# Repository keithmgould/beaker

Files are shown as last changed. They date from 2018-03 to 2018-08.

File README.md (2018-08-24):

# Beaker Robot

## Brief Compute Breakdown

### Raspberry Pi

This is used for Beaker's "high level" control, in particular any neural network control algorithms are stored here.

### Arduino Mega

This is used for Beaker's "low level" control. It can take commands from the "high level" Raspberry Pi. It handles all the details of Beaker's physical components, like input sensors, telemetry transmission, and motor control.

## Software Breakdown

Since Beaker utilizes both an Arduino and a Raspberry Pi, code is broken up into two main directories named (drum roll...) arduino and raspberry_pi.

### Arduino

#### arduino/lib

The bulk of Beaker's Arduino code is housed in the `arduino/lib` directory. Here you will find literally all functionality wrapped in classes. Each lib has a header comment explaining the libs role.

#### arduino/controllers

The controllers realize balance and basic functionality. There are some oldies but goodies, like pid_control. Each controller
has a header-comment explaining what it does. Of note is the `rPI_control`, which is the controller that acts as a middle-man 
between the Raspberry Pi and Beaker's body. This is the controller used for any neural-network control.

When working with any of the non-neural network controllers, such as PID, you can easily interact with Beaker wirelessly via the 
`raspberry_pi/terminal/arduino.py` script. Once the arduino app is loaded and running, ssh into the pi, run the script and type
`H` to see a list of options for how to interact (and tune) the controller you are playing with. 

#### arduino/system_checks

The system checks directory holds a bunch of arduino scripts that allow the developer to
interactively test out the functionality of Beaker as well as the low-level libraries that makes Beaker 
work. For example, there is an 'encoders' script that lets the developer turn the wheels (by hand)
and see in the serial output that the encoders are working. It's important that the 
underlying code works before attempting to lay on more complicated algorithms. The README
in System_checks has some suggestions about the ordering in which someone performs the checks.
Note that these are not needed to run before each use. They are there in case things go wrong,
and you want to find out where exactly in hardware/software things are failing.

### Raspberry_Pi

This directory holds the python-based raspberry pi scripts. These are primarily Tensorflow-based neural-networks
that usilize the `rPI_control` arduino app mentioned above.

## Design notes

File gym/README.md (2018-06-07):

Want to use a "realistic" Beaker Bot in simulation with the help of the Bullet Physics engine,
and OpenAI Gym? Great!

##### Primary Files

0. beaker.urdf - the Universal Robot Description File. describes the actual model of Beaker.
0. beakerBot.py - the BeakerBot class that wraps the URDF file.
0. beakerEnv.py - the gym environment that makes use of the BeakerBot class
0. client.py - holds your control algorithm

#### Using it

```
$python3 pidClient.py
```

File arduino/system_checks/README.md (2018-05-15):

## System Checks

These System Checks are isolated pieces of Beaker's functionality, 
meant to ensure higher level, more abstract code is sitting on sane code.

They are not tests (not unit tests, etc..), they are meant to be run on 
Beaker's arduino and print information on Serial Out to prove out basic 
low-level functionality.

Each system check tells you exactly what to check for in the comments.

### Suggested Order of System Checks if using Serial for Motor Control:

1. Encoders
2. rawSerialMotor
3. serialMotor
4. wheels_pid
5. wheels

### Suggested Order of System Checks if using PWM for Motor Control:

1. Encoders
2. rawPWMMotor
3. servoMotor
4. wheels_pid
5. wheels

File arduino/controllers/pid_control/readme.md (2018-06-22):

# Classic Control

Taking the below concept and applying PID to each of the states, rather than just P on each state.

In short, given four element vector that defines the state:

theta, thetaDot, phi, phiDot,

We can apply a PID controller to each of these elements, and sum them together:

outTheta = thetaPid(theta)
outThetaDot = thetaDotPid(theta)
outphi = phiPid(phi)
outphiDot = phiDotPid(phiDot)

then final command is a sum of these:

outTheta + outThetaDot + outPhi + outPhiDot

This command is interpreted as an acceleration, aka a change in desired wheel velocity.

# Original P4 Concept

http://www.geology.smu.edu/~dpa-www/robo/nbot/bal2.txt

David Anderson wrote the following:

---

The Algorithm for two-wheel balancing robot nBot.

The balancing algorithm measures two outputs from the
robot and calculates the torque forces from the motors
needed for balance.  Here is an ascii-art block diagram:

               +---------------------+--------------+
    +--------< | Motor shaft encoder |              |
    |          +---------------------+   Motor PWM  | <-----+
    |    +---< | Angle sensor        |              |       |
    |    |     +---------------------+--------------+       |
    |    |                                                  |
    |    |     +-------+      |\ angle                      |
    |    |     |       |      | \ velocity                  |
    |    +-----| Deriv |------|K1-----+                     |
    |    |     |       |      | /      \                    |
    |    |     +-------+      |/        \                   |
    |    |                               +-----+            |
    |    |                    |\ angle   |      \           |
    |    |                    | \ pos    |       \          |
    |    +--------------------|K2--------+        \         |
    |                         | /        |         \        |
    |                         |/         |          \       |
    |                                    |  SUM      +------+
    |          +-------+      |\ wheel   |          /
    |          |       |      | \velocity|         /
    +----------| Deriv |------|K3--------+        /
    |          |       |      | /        |       /
    |          +-------+      |/         |      /
    |                                    +-----+
    |                         |\ wheel  /
    |                         | \ pos  /
    +-------------------------|K4-----+
                              | /
                              |/

The boxes labled "Deriv" calculate the derivative of the inputs
by subtracting the last sample from the current sample.  For the
shaft encoders this gives the wheel velocity, and for the angle
sensor this gives the angle velocity.  The four triangles labeled
K1 through K4 are the "knobs" that apply gain to the four feedback
signals.  They are then summed together and fed back to the robot
as the PWM motor voltage.

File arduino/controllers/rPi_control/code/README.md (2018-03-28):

## Role: The Arduino acts as Beaker's nervous system:

0. receives (and buffers) the motor quadrature encoders interrupt signals.
0. commands the motors
0. communicates with the IMU
0. communicates with the winch (Add link to repo here)
0. prepares the "state" for the Raspberry Pi (brain) and sends it up upon  request

## Why Not Skip the Arduino?

It's probably possible to skip the Arduino entirely. The reason I didn't is because having
dedicated hardware (and processing power) to lower level functions seemed (and seems) like
a good idea. The quad-encoders for example, send interrupts 300 times per single
revolution of a wheel. Two wheels mean 600 interrupts per second. I'd rather keep that
noise away from the hardware handling the neural network.

## Relevant Files:

0. arduino.ino - the main arduino file to compile (and upload to robot)
0. servoMotor.cpp - small class to encapsulate controlling motors and quad encoders
0. constants.cpp - holds the (you guessed it) constants for the ardduino app

# Functionality Checks:

These are micro progams that load just enough code to test specific parts of
Beaker's hardware.

## Dependencies:

0. Wire.h - allows I2C communication. (this is a core Arduino lib)
0. SabertoothSimplified.h - https://www.dimensionengineering.com/info/arduino

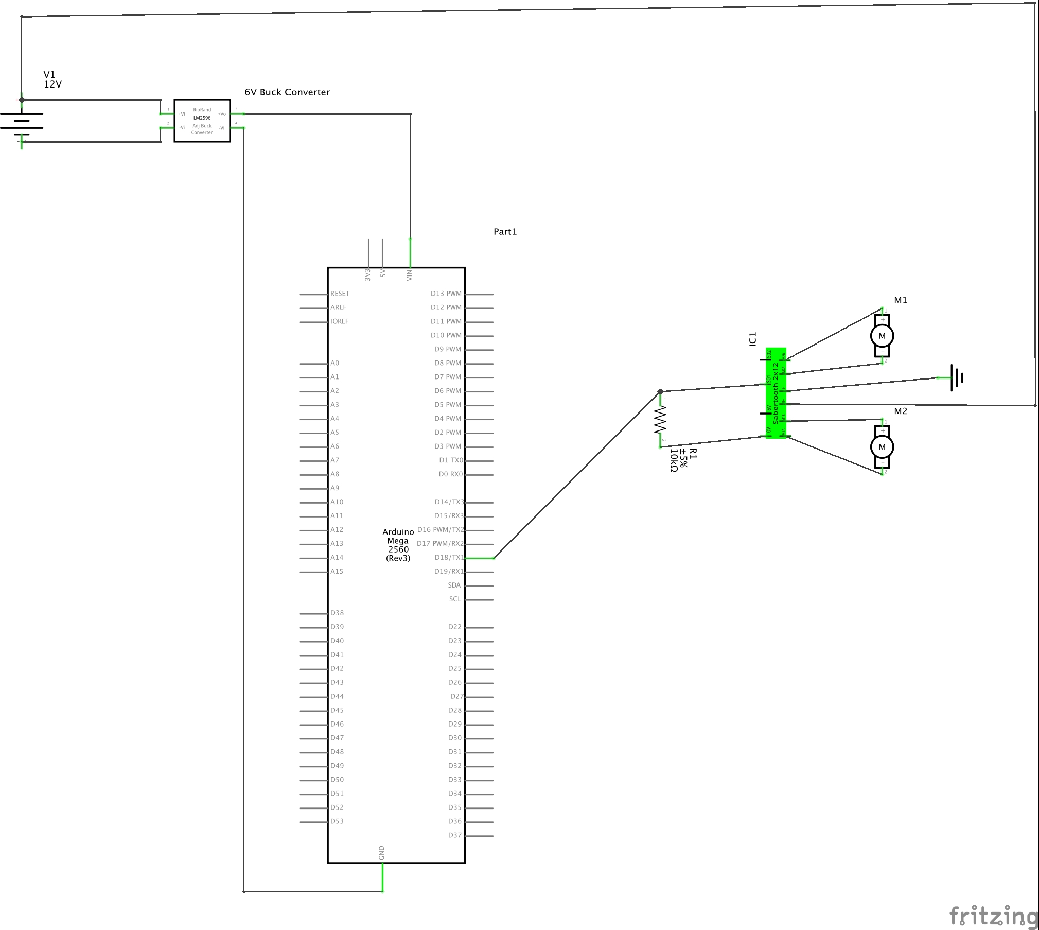
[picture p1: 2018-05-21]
schematics/main_schema.jpg

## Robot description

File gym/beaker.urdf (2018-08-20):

<?xml version="1.0"?>
<robot name="beaker">

    <!-- colors ................................................................. -->
    <material name="red">
      <color rgba="0.8 0 0 1"/>
    </material>
  
   <material name="green">
      <color rgba="0 0.8 0 0.75"/>
    </material>
  
    <material name="blue">
      <color rgba="0 0 0.8 1"/>
    </material>
  
    <material name="orange">
      <color rgba="0.8 0.4 0 0.75"/>
    </material>
  
    <material name="pink">
      <color rgba="1 0.5 0.5 1"/>
    </material>
    
    <material name="gray">
      <color rgba="0.7 0.7 0.7 1"/>
    </material>
    <!-- main body (base) .................................................................-->
  
    <link name="body">
      <visual>
        <geometry>
          <box size="0.1016 0.0254 0.6604"/>
        </geometry>
        <origin xyz="0 0 0.3302" />
        <material name="gray"/>
      </visual>
  
      <!-- axle -->
      <visual>
        <geometry>
          <cylinder length="0.17" radius=".01"/>
        </geometry>
        <origin rpy="0 1.5707963 0" xyz="0 0 0.01905"/>
        <material name="gray"/>
      </visual>
  
      <collision>
        <geometry>
          <box size="0.1016 0.0254 0.6604"/>
        </geometry>
        <origin xyz="0 0 0.3302" />
      </collision>
      <inertial>
        <origin rpy="0 0 0" xyz="0 0 0.2159"/>
        <mass value="1.767" />
        <inertia ixx="0.01" ixy="0.0" ixz="0.0" iyy="0.01" iyz="0.0" izz="0.01"/>
      </inertial>
    </link>

    <!-- right Wheel .................................................................-->
    <link name="right_wheel">
      <visual>
        <geometry>
          <cylinder length="0.0254" radius="0.042"/>
        </geometry>
        <origin rpy="0 1.5708 0"/>
        <material name="green"/>
      </visual>
      <collision>
        <geometry>
          <cylinder length="0.0254" radius="0.042"/>
        </geometry>
        <origin rpy="0 1.5708 0"/>
      </collision>
      <inertial>
        <mass value=".1" />
        <inertia ixx="0.00004453" ixy="0.0" ixz="0.0" iyy="0.00004453" iyz="0.0" izz="0.00007938"/>
      </inertial>
    </link>
  
    <joint name="base_to_right_wheel" type="revolute">
      <limit lower="-0.0756" upper="0.0756" effort="1000" velocity="1000"/>
      <origin xyz="0.09398 0 0.01905"/>
      <parent link="body"/>
      <child link="right_wheel"/>
      <axis xyz="1 0 0"/>
    </joint>
  

    <!-- left Wheel .................................................................-->
    <link name="left_wheel">
      <visual>
        <geometry>
          <cylinder length="0.0254" radius="0.042"/>
        </geometry>
        <origin rpy="0 1.5708 0"/>
        <material name="red"/>
      </visual>
      <collision>
        <geometry>
          <cylinder length="0.0254" radius="0.042"/>
        </geometry>
        <origin rpy="0 1.5708 0"/>
      </collision>
      <inertial>
        <mass value=".1" />
        <inertia ixx="0.00004453" ixy="0.0" ixz="0.0" iyy="0.00004453" iyz="0.0" izz="0.00007938"/>
      </inertial>
    </link>
  
    <joint name="base_to_left_wheel" type="revolute">
      <limit lower="-0.0756" upper="0.0756" effort="1000" velocity="1000"/>
      <origin xyz="-0.09398 0 0.01905"/>
      <parent link="body"/>
      <child link="left_wheel"/>
      <axis xyz="1 0 0"/>
    </joint>

</robot>

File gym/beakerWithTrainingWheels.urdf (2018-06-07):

<?xml version="1.0"?>
<robot name="beaker">
  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
  <link name="body">
    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

    <inertial>
      <origin rpy="0 0 0" xyz="0 0 0.2159"/>
      <mass value="1.767" />

      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
    </inertial>
  </link>

  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
  <link name="face">
    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
    <inertial>
      <mass value="0" />
      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
    </inertial>
  </link>
  <joint name="face_joint" type="fixed">
    <parent link="body"/>
    <child link="face"/>
  </joint>

  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
  <link name="right_wheel">

    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

    <inertial>
      <origin rpy="0 0 0" xyz="0 0 0.2159"/>
      <mass value="0.09" />

      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
    </inertial>
  </link>

  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
  <joint name="base_to_right_wheel" type="continuous">
    <parent link="body"/>
    <child link="right_wheel"/>
    <origin xyz="0.09398 0.0 0.01905" />
    <axis xyz="1 0 0"/>
  </joint>

  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
  <link name="right_wheel_stripe">
    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
    <inertial>
      <mass value="0" />
      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
    </inertial>
  </link>
  <joint name="right_wheel_to_stripe" type="fixed">
    <parent link="right_wheel"/>
    <child link="right_wheel_stripe"/>
  </joint>

  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
  <link name="left_wheel">
    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

    <inertial>
      <origin rpy="0 0 0" xyz="0 0 0.2159"/>
      <mass value="0.09" />

      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
    </inertial>
  </link>

  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
  <joint name="base_to_left_wheel" type="continuous">
    <parent link="body"/>
    <child link="left_wheel"/>
    <origin xyz="-0.09398 0.0 0.01905" />
    <axis xyz="1 0 0"/>
  </joint>

  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
  <link name="left_wheel_stripe">
    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
    <inertial>
      <mass value="0" />
      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
    </inertial>
  </link>
  <joint name="left_wheel_to_stripe" type="fixed">
    <parent link="left_wheel"/>
    <child link="left_wheel_stripe"/>
  </joint>

  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
  <link name="front_training_wheel_strut">
    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 

    <inertial>
      <origin rpy="0 0 0" xyz="0 0 0"/>
      <mass value="0.000001" />
      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
    </inertial>
  </link>
  <joint name="front_strut_joint" type="fixed">
    <parent link="body"/>
    <child link="front_training_wheel_strut"/>
  </joint>

  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
  <link name="left_wheel_front">
    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

    <inertial>
      <origin rpy="0 0 0" xyz="0 0 0.2159"/>
      <mass value="0.001" />

      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
    </inertial>
  </link>

  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
  <joint name="front_strut_to_front_left_wheel" type="continuous">
    <parent link="front_training_wheel_strut"/>
    <child link="left_wheel_front"/>
    <origin xyz="-0.09398 0.42 0.01905" />
    <axis xyz="1 0 0"/>
  </joint>

  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
  <link name="right_wheel_front">
    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

    <inertial>
      <origin rpy="0 0 0" xyz="0 0 0.2159"/>
      <mass value="0.001" />

      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
    </inertial>
  </link>

  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
  <joint name="front_strut_to_front_right_wheel" type="continuous">
    <parent link="front_training_wheel_strut"/>
    <child link="right_wheel_front"/>
    <origin xyz="0.09398 0.42 0.01905" />
    <axis xyz="1 0 0"/>
  </joint>

    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
  <link name="right_wheel_front_stripe">
    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
    <inertial>
      <mass value="0" />
      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
    </inertial>
  </link>
  <joint name="right_wheel_front_to_stripe" type="fixed">
    <parent link="right_wheel_front"/>
    <child link="right_wheel_front_stripe"/>
  </joint>

  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
   <link name="rear_training_wheel_strut">
    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 
    <inertial>
      <origin rpy="0 0 0" xyz="0 0 0"/>
      <mass value="0.0001" />
      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
    </inertial>
  </link>
  <joint name="rear_strut_joint" type="fixed">
    <parent link="body"/>
    <child link="rear_training_wheel_strut"/>
  </joint>

  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
  <link name="right_wheel_rear">
    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

    <inertial>
      <origin rpy="0 0 0" xyz="0 0 0.2159"/>
      <mass value="0.001" />

      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
    </inertial>
  </link>

  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
  <joint name="rear_strut_to_rear_right_wheel" type="continuous">
    <parent link="rear_training_wheel_strut"/>
    <child link="right_wheel_rear"/>
    <origin xyz="0.09398 -0.42 0.01905" />
    <axis xyz="1 0 0"/>
  </joint>

  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
  <link name="right_wheel_rear_stripe">
    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
    <inertial>
      <mass value="0" />
      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
    </inertial>
  </link>
  <joint name="right_wheel_rear_to_stripe" type="fixed">
    <parent link="right_wheel_rear"/>
    <child link="right_wheel_rear_stripe"/>
  </joint>

  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
  <link name="left_wheel_rear">
    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

    <inertial>
      <origin rpy="0 0 0" xyz="0 0 0.2159"/>
      <mass value="0.001" />

      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
    </inertial>
  </link>

  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
  <joint name="rear_strut_to_rear_left_wheel" type="continuous">
    <parent link="rear_training_wheel_strut"/>
    <child link="left_wheel_rear"/>
    <origin xyz="-0.09398 -0.42 0.01905" />
    <axis xyz="1 0 0"/>
  </joint>

  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
  <link name="left_wheel_rear_stripe">
    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
    <inertial>
      <mass value="0" />
      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
    </inertial>
  </link>
  <joint name="left_wheel_rear_to_stripe" type="fixed">
    <parent link="left_wheel_rear"/>
    <child link="left_wheel_rear_stripe"/>
  </joint>

</robot>

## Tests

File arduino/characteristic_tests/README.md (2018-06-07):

## Characteristic Tests

This directory holds tests that are used to help determine constants exhibited by Beaker that 
can be used in the virtual model of Beaker, to help that model be more realistic.

0. wheelSlowdown brings the wheels up to 10 rads/sec, then times how long it takes for them to stop once the power is shut off. This time can be used when setting friction values in the model.

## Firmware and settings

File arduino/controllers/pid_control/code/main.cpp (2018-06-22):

#include <Adafruit_Sensor.h>            // IMU
#include <Adafruit_BNO055.h>            // IMU
#include <Wire.h>                       // I2C for IMU
#include <EEPROM.h>
#include <StandardCplusplus.h>
#include <stdlib.h>
#include <string>
#include <sstream>                      // stringstream
#include "../../../lib/includes.h"     // common Beaker functionality

Pid thetaPid(POSITION_CONTROL_TIMESTEP);
Pid thetaDotPid(POSITION_CONTROL_TIMESTEP);
Pid xPosPid(POSITION_CONTROL_TIMESTEP);
Pid phiDotPid(POSITION_CONTROL_TIMESTEP);

Imu my_imu;
Wheels wheels;
PiTalk piTalk;
Waiter outerWaiter(POSITION_CONTROL_TIMESTEP);
Waiter innerWaiter(MOTOR_CONTROL_TIMESTEP);
bool motorsOn = true;
float momentumConstant = 0;

void leftEncoderEvent(){ wheels.leftEncoderEvent(); }
void rightEncoderEvent(){ wheels.rightEncoderEvent(); }

void printStuff(float dt, float newRadPerSec, float radPerSecDelta, float phiDotAvg, float thetaTerm, float thetaDotTerm, float xPosTerm, float phiDotTerm){
  String log = String(dt);

  // raw states
  log += "," + String(my_imu.getTheta(),4) + "," + String(my_imu.getThetaDot(),4);
  log += "," + String(wheels.getTotalPhi(),4) + "," + String(phiDotAvg,4);

  // calibrations
  log += "," + String(my_imu.getThetaOffset(),4);

  // final result
  log += "," + String(newRadPerSec,4);
  
  // PID term components
  log += "," + String(thetaPid.getTermString());
  log += "," + String(thetaDotPid.getTermString());
  log += "," + String(xPosPid.getTermString());
  log += "," + String(phiDotPid.getTermString());

  // PID final term  
  log += "," + String(thetaTerm,4);
  log += "," + String(thetaDotTerm,4);
  log += "," + String(xPosTerm,4);
  log += "," + String(phiDotTerm,4);

  // Extra
  log += "," + String(wheels.getPhiDot(),4);
  log += "," + String(radPerSecDelta,4);
  log += "," + String(momentumConstant,4);

  Serial3.println(log);
}

// Local memory only. Not EEPROM
void zeroAllParameters(bool tellPi){
  thetaPid.updateParameters(0,0,0);
  thetaDotPid.updateParameters(0,0,0);
  xPosPid.updateParameters(0,0,0);
  phiDotPid.updateParameters(0,0,0);
  wheels.updateRadsPerSec(0);
  momentumConstant = 0;

  if(tellPi){ piTalk.sendToPi("Values Zeroed."); }
}

// in EEPROM
void storeAllParameters(){
  unsigned int addr = 0;
  addr = thetaPid.storeParameters(addr);
  addr = thetaDotPid.storeParameters(addr);
  addr = xPosPid.storeParameters(addr);
  addr = phiDotPid.storeParameters(addr);
  addr = EepromHelper::storeFloat(momentumConstant, addr);

  piTalk.sendToPi("Values Saved to EEPROM.");
}

// from EEPROM
void loadAllParameters(){
  unsigned int addr = 0;
  addr = thetaPid.loadParameters(addr);
  addr = thetaDotPid.loadParameters(addr);
  addr = xPosPid.loadParameters(addr);
  addr = phiDotPid.loadParameters(addr);
  EepromHelper::loadFloat(momentumConstant, addr);

  piTalk.sendToPi("Values Loaded from EEPROM.");
}

void showParamValues(){
  String response = "(T)heta: " + thetaPid.getParamString() + "\n";
  response += "theta(D)ot: " + thetaDotPid.getParamString() + "\n";
  response += "(X)Pos: " + xPosPid.getParamString() + "\n";
  response += "(P)hiDot: " + phiDotPid.getParamString() + "\n";
  response += "MotorsOn: " + String(motorsOn) + "\n";
  response += "MomentumConstant: " + String(momentumConstant) + "\n";

  piTalk.sendToPi(response);
}

void updatePidParameters(int component, std::string message){
  float paramVals[3] = {}; // all zeros
  piTalk.stringToFloats(message, paramVals);
  switch(component){
    case 0:
      thetaPid.updateParameters(paramVals[0], paramVals[1], paramVals[2]);
      break;
    case 1:
      thetaDotPid.updateParameters(paramVals[0], paramVals[1], paramVals[2]);
      break;
    case 2:
      xPosPid.updateParameters(paramVals[0], paramVals[1], paramVals[2]);
      break;
    case 3:
      phiDotPid.updateParameters(paramVals[0], paramVals[1], paramVals[2]);
      break;
  }

  piTalk.sendToPi("Updated PID Parameters.");
}

void turnMotorsOn(){ motorsOn = true; piTalk.sendToPi("Motors Turned ON."); }
void turnMotorsOff(){ motorsOn = false; piTalk.sendToPi("Motors Turned OFF."); }

void updateMomentumConstant(std::string message){
  float newMC = String(message.c_str()).toFloat();
  momentumConstant = newMC;
  piTalk.sendToPi("Updated Momentum Constant.");
}

void showHelp(){
  String response = "T: update theta PID terms. Ex: T0.5 -2.4 8.2\n";
  response += "D: update thetaDot PID terms. Ex: D0.5 -2.4 8.2\n";
  response += "X: update xPos PID terms. Ex: X0.5 -2.4 8.2\n";
  response += "P: update phiDot PID terms. Ex: P0.5 -2.4 8.2\n";
  response += "A: update momentumConstant. Ex: A0.5\n";
  response += "L: load PID values from EEPROM\n";
  response += "S: save PID values to EEPROM\n";
  response += "V: show currently used Param Values\n";
  response += "Z: zero out all PID Values.\n";
  response += "J: enable motors. (Pay attention to motor commands)\n";
  response += "K: disable motors. (Ignore motor commands)\n";
  response += "H: this help\n";

  piTalk.sendToPi(response);
}

void handlePiTalk(char command, std::string message){
  switch(command){
    case 'T': updatePidParameters(0, message); break;
    case 'D': updatePidParameters(1, message); break;
    case 'X': updatePidParameters(2, message); break;
    case 'P': updatePidParameters(3, message); break;
    case 'A': updateMomentumConstant(message); break;
    case 'S': storeAllParameters(); break;
    case 'L': loadAllParameters(); break;
    case 'V': showParamValues(); break;
    case 'Z': zeroAllParameters(true); break;
    case 'J': turnMotorsOn(); break;
    case 'K': turnMotorsOff(); break;
    case 'H': showHelp(); break;
  }
}

void emergencyStop(){
  wheels.updateRadsPerSec(0);
  zeroAllParameters(false);
  Outputs::beep(100,100);
  Outputs::beep(100,100);
  Outputs::beep(100,100);
}

void setup() {
  // thetaPid.setClearAccumulatorWhenCrossingZero(true);

  piTalk.setup(&wheels, &my_imu, &handlePiTalk);
  Serial.begin(115200); while (!Serial) {;}
  Serial3.begin(115200); while (!Serial3) {;} // bluetooth
  Serial.println("\n\nBeginning initializations...");
  my_imu.setup();
  attachInterrupt(digitalPinToInterrupt(LH_ENCODER_A), leftEncoderEvent, CHANGE);
  attachInterrupt(digitalPinToInterrupt(RH_ENCODER_A), rightEncoderEvent, CHANGE);
  Serial.println("Setting up interrupts...Done!");
  wheels.initialize();
  Outputs::init();
}

void loop(){
  // inner loop behavior
  if(innerWaiter.isTime()){
    float innerDt = innerWaiter.starting();
    wheels.spin(innerDt);
    my_imu.pushThetaDotData();
  }

  // outer loop behavior
  if(outerWaiter.isTime()){
    float outerDt = outerWaiter.starting();
    my_imu.update();
    if(my_imu.isEmergency()) { emergencyStop(); }

    float phiDotAvg = wheels.getPhiDotAvg();
    float xPos = wheels.getX();
    float theta = my_imu.getTheta();

    float thetaTerm = thetaPid.generateCommand(theta);
    float thetaDotTerm = thetaDotPid.generateCommand(my_imu.getThetaDot());
    float xPosTerm = xPosPid.generateCommand(wheels.getX());
    float phiDotTerm = phiDotPid.generateCommand(phiDotAvg);

    // If the xPosTerm did its job and got us leaning back towards X=0, 
    // then stop trying to accelerate away from X=0.
    float momentum = momentumConstant * fabs(phiDotAvg);

    if(xPos > 0 && theta < -momentum){ xPosTerm = 0; }
    if(xPos < 0 && theta > momentum){ xPosTerm = 0; }

    float radPerSecDelta = thetaTerm + thetaDotTerm + xPosTerm + phiDotTerm;
  
    radPerSecDelta = -radPerSecDelta;

    float newRadPerSec = wheels.getTargetRadsPerSec();

    newRadPerSec += radPerSecDelta;

    newRadPerSec = constrain(newRadPerSec, -10,10);

    if(motorsOn){
      wheels.updateRadsPerSec(newRadPerSec);  
    }else{
      wheels.updateRadsPerSec(0);
    }

    printStuff(outerDt, newRadPerSec, radPerSecDelta, phiDotAvg, thetaTerm, thetaDotTerm, xPosTerm, phiDotTerm);
    piTalk.checkForPiCommand();
  }
}

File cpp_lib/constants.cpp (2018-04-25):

// pi / 180, for degrees to radians
#define PI_OVER_ONE_EIGHTY 0.017453292519943

// LED on side of robot
#define INDICATOR 8

// pins for the motor encoders
#define RH_ENCODER_A 3 // interupt pin
#define RH_ENCODER_B 5
#define LH_ENCODER_A 2 // interupt pin
#define LH_ENCODER_B 4

// pin for piezo buzzer
#define BUZZER_PIN 9

// pins for radio
#define RADIO_CE 6
#define RADIO_CSN 7

// Duration (in millisecs) for each loop.
// MAKE SURE: that the position control is
// 3-4 times slower than motor control
#define MOTOR_CONTROL_TIMESTEP 5
#define POSITION_CONTROL_TIMESTEP 20

// Minimum/Maximum values to send to motor drivers
// Should ALWAYS be between -1 and 1.
// To constrain to 50% power use -.5 and .5
#define MINIMUM_GAIN -1
#define MAXIMUM_GAIN 1

// Used by Wheels object
#define THETA_OFFSET 0.01 // due to minorly non-level IMU
#define MOTOR_P_PARAM 0.015
#define MOTOR_I_PARAM 0
#define MOTOR_D_PARAM 0.05

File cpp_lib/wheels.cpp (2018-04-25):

#include "./servoMotor.cpp"
#include "./pid.cpp"            // Basic PID algorithm

class Wheels {
  private:

  Waiter waiter = Waiter(MOTOR_CONTROL_TIMESTEP);
  Pid leftMotorPid = Pid(MOTOR_CONTROL_TIMESTEP);
  Pid rightMotorPid = Pid(MOTOR_CONTROL_TIMESTEP);

  // bunch of variables for timing...
  float leftPhi, leftLastPhi, leftPhiDot;
  float rightPhi, rightLastPhi, rightPhiDot;

  // actual commands sent to motors
  float leftCommand, rightCommand;

  ServoMotor motorLeft  = ServoMotor(LH_ENCODER_A, LH_ENCODER_B, 1);
  ServoMotor motorRight = ServoMotor(RH_ENCODER_A, RH_ENCODER_B, -1);

  // calculates and stores phi and phiDot
  // rads and rads/sec
  void updateLeftPhi(float dt){
    leftPhi = motorLeft.getPhi();
    leftPhiDot = (1000.0 / dt) * (leftPhi - leftLastPhi) / (dt / MOTOR_CONTROL_TIMESTEP);
    leftLastPhi = leftPhi;
  }

  void updateRightPhi(float dt){
    rightPhi = motorRight.getPhi();
    rightPhiDot = (1000.0 / dt) * (rightPhi - rightLastPhi) / (dt / MOTOR_CONTROL_TIMESTEP);
    rightLastPhi = rightPhi;
  }

  public:

  Wheels(){
    // Serial1 used for communication with motor driver
    Serial1.begin(9600);
    while (!Serial1) {;}

    leftPhi = leftLastPhi = leftPhiDot = leftCommand = 0;
    rightPhi = rightLastPhi = rightPhiDot = rightCommand = 0;
  }

  void initialize(){
    updateRadsPerSec(0);
    updatePids(MOTOR_P_PARAM,MOTOR_I_PARAM,MOTOR_D_PARAM);
  }

  void rightEncoderEvent(){
    motorRight.encoderEvent();
  }

  void leftEncoderEvent(){
    motorLeft.encoderEvent();
  }

  // in meters. Average of both wheels
  float getX(){
    return (motorLeft.getDistance() + motorRight.getDistance()) / 2.0;
  }

  float getPhi(){ return (leftPhi + rightPhi) / 2.0; }  // rads. avg of 2 whls
  float getPhiDot(){ return (leftPhiDot + rightPhiDot) / 2.0; }  // rads. avg of 2 whls
  long getLeftPhi(){ return leftPhi; }                  // rads
  long getLeftPhiDot(){ return leftPhiDot; }            // rads/sec
  long getRightPhi(){ return rightPhi; }                // rads
  long getRightPhiDot(){ return rightPhiDot; }          // rads/sec

  long getLeftMotorEdgeCount(){
    return motorLeft.getEdgeCount();
  }

  long getRightMotorEdgeCount(){
    return motorRight.getEdgeCount();
  }

  void updatePhi(float dt){
    updateRightPhi(dt);
    updateLeftPhi(dt);
  }



  // float logs[2][200];
  // long counter = 0;
  // bool storeLogs = false;

  void spin(long dt) {
    updatePhi(dt);

    float leftCommandDelta = leftMotorPid.generateCommand(leftPhiDot, dt);
    float rightCommandDelta = rightMotorPid.generateCommand(rightPhiDot, dt);

    leftCommand += leftCommandDelta;
    rightCommand += rightCommandDelta;

    motorLeft.updatePower(leftCommand);
    motorRight.updatePower(rightCommand);

    // if(storeLogs){
    //   logs[0][counter] = leftPhiDot;
    //   logs[1][counter] = rightPhiDot;
    //   counter++;
    //   if(counter >= 195){
    //     storeLogs = false;
    //     counter = 0;
    //     Serial.println("Log Time!");
    //     for(int i = 0;i<195;i++){
    //       String foo =  String(i) + "," +String(logs[0][i],5) + "," + String(logs[1][i],5);
    //       Serial.println(foo);
    //     }
    //   }
    // }
  }

  void updatePids(float kp, float ki, float kd){
    leftMotorPid.updateParameters(kp, ki, kd);
    rightMotorPid.updateParameters(kp, ki, kd);
  }

  void updateRadsPerSec(float rps){
    leftMotorPid.updateSetpoint(rps);
    rightMotorPid.updateSetpoint(rps);
    // counter = 0;
    // storeLogs = true;
  }
};

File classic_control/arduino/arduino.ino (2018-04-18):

// CLASSIC CONTROL -- PID

#include <StandardCplusplus.h>
#include <sstream>      // std::istringstream

#include <cmath>

#include "../../cpp_lib/constants.cpp"
#include "../../cpp_lib/servoMotor.cpp"
#include "../../cpp_lib/state.cpp"
#include "../../cpp_lib/pid.cpp"

ServoMotor motorLeft(LH_ENCODER_A,LH_ENCODER_B, 1);
ServoMotor motorRight(RH_ENCODER_A,RH_ENCODER_B, -1);

State state(motorLeft, motorRight);

// motor control (inner) PID
Pid motorPid(MOTOR_CONTROL_TIMESTEP);

// position control (outer) PID
Pid positionPid(POSITION_CONTROL_TIMESTEP);

float motorCommand = 0; // holds the final command to motor

// following variables used to control the loop times
long positionTimeMarker = 0;
long motorTimeMarker = 0;
long lastPrintNow = 0; // only used to verify final loop time

float previousGain = 0;

// vars to hold incoming serial messages from Pi
char tmp_char;
std::string str;

void printStatus(){
  String str = "";
  long printNow = millis();
  str += String(printNow - lastPrintNow);
  str += ", " + String(theta,5);
  str += ", " + String(accumulatedError, 5);
  str += ", " + String(deltaError, 5);
  str += ", " + String(motorCommand, 1);
  lastPrintNow = printNow;
  Serial.println(str);
}

void turnIndicatorLightOff(){
  digitalWrite(INDICATOR, LOW);
}

void turnIndicatorLightOn(){
  digitalWrite(INDICATOR, HIGH);
}

void turnBuzzerOn(){
  digitalWrite(BUZZER_PIN, HIGH);
}

void turnBuzzerOff(){
  digitalWrite(BUZZER_PIN, LOW);
}

void beep(int durationOn, int durationOff){
  turnBuzzerOn();
  delay(durationOn);
  turnBuzzerOff();
  delay(durationOff);
}

void playInitSong(){
  beep(100, 50);
  beep(100, 50);
  beep(100, 50);
}

void updateMotor(){
  // safety first. ensure gain between these values
  float newGain = constrain(motorCommand, -1, 1);

  if(newGain == previousGain){ return; }

  previousGain = newGain;

  motorLeft.updatePower(newGain);
  motorRight.updatePower(newGain);
}

void stopMotors() {
  motorCommand = 0;
  updateMotor();
}

void leftEncoderEvent() {
  motorLeft.encoderEvent();
}

void rightEncoderEvent() {
  motorRight.encoderEvent();
}

// kill motors and blink status indicator
// FOREVER
void errorMode(const char* input) {
  Serial.println("\n!!!!!!!!!!!!!!!!!!!!!! In Error Mode!");
  stopMotors();
  Serial.print("Error: ");
  Serial.println(input);
  while(true){
    turnIndicatorLightOn();
    turnBuzzerOn();
    delay(300);
    turnIndicatorLightOff();
    turnBuzzerOff();
    delay(300);
  }
}

void updatePIDValues(std::string message){
  Serial.println("Updating PID Values!!!");
  Serial.println(message.c_str());

  float values[3];
  std::istringstream ss( message );
  std::copy(
    std::istream_iterator <float> ( ss ),
    std::istream_iterator <float> (),
    values
    );


  kP = values[0];
  kI = values[1];
  kD = values[2];
}

void generateMotorCommand(){

}

void generatePositionCommand(){
  // this is the crux of the PID controller: adding togethe the P,I,D components
  float finalCommand = kP * currentError + kI * accumulatedError + kD * deltaError;

  // ensure we stay within bounds of motor controller.
  motorCommand = constrain(finalCommand, -1, 1);
}

void sendToPi(char code, String message){
  String final;
  final = String(code) + message + "!";
  Serial.print("sending to Pi: ");
  Serial.println(final.c_str());
  Serial2.write(final.c_str());
}

// this is used if Arduino received an unrecognized command. The assumption is
// that the PI sent something valid, but there was a transmission error.
void resendCommand(){
  String message = " ";
  sendToPi('X', message);
}

void handle_command_from_pi(std::string message){
  Serial.print("got the message from Pi: ");
  Serial.println(message.c_str());
  char command;
  command = message[0];
  switch (command){
    case 'S': playInitSong();
              break;
    case 'U': updatePIDValues(message.substr(1));
              break;
    default: resendCommand(); // must have been a transmission error?
  }
}

// update data from Pi.
// If full command is here, process it.
void checkForPiCommand(){
  while(Serial2.available()) {
    tmp_char = Serial2.read();
    if(tmp_char == '!'){
      handle_command_from_pi(str);
      str = "";
    }else{
      str += tmp_char;
    }
  }
}

long wait_loop_ms(long &marker, int timestep){
  long nowish = 0;
  long timeDelta = 0;

  while(true){
    nowish = millis();
    timeDelta = nowish - marker;
    if(timeDelta < timestep){ continue; }
    marker = nowish;
    break;
  }

  return timeDelta;
}

long wait_POSITION_CONTROL_TIMESTEP_ms(){
  return wait_loop_ms(positionTimeMarker, POSITION_CONTROL_TIMESTEP);
}

long wait_MOTOR_CONTROL_TIMESTEP_ms(){
  return wait_loop_ms(motorTimeMarker, MOTOR_CONTROL_TIMESTEP);
}

void setup(){

  // these should not need to change
  motorPid.updateParameters(0.1, 0.1, 0.1);

  // indicator pin is an output for LED
  pinMode(INDICATOR, OUTPUT);
  pinMode(BUZZER_PIN, OUTPUT);

  // turn off indicator light while we setup
  turnIndicatorLightOff();
  turnBuzzerOff();

    // Open console serial communications
  Serial.begin(115200);
  while (!Serial) {;}
  Serial.println("\n\nBeginning initializations...");

  // Open serial comm to talk to RaspPi.
  Serial.print("Initializing comm to Rasp Pi...");
  Serial2.begin(115200);
  while (!Serial2) {;}
  Serial.println("Done!");

    // initialize motor encoders and interrupts
  Serial.print("Initializing motor encoders...");
  motorLeft.init();
  motorRight.init();
  delay(100);
  Serial.println("Done!");

  // TODO: add these to motor inits??
  Serial.print("Initializing motor interrupts...");
  attachInterrupt(digitalPinToInterrupt(LH_ENCODER_A), leftEncoderEvent, CHANGE);
  attachInterrupt(digitalPinToInterrupt(RH_ENCODER_A), rightEncoderEvent, CHANGE);
  Serial.println("Done!");

  // Sabertooth motor driver commanded over Serial
  Serial.print("Initializing motor driver serial connection...");
  Serial1.begin(9600);
  while (!Serial1) {;}
  Serial.println("Done!");

  Serial.print("Initializing state and IMU...");
  if(state.initialize()){
    Serial.println("Done!");
  }else{
    Serial.println("Inertial Sensor failed, or not present. Halting.");
    while(true){}
  }

  // Turn on indicator light because we are ready to rock.
  Serial.println("Done Initializing like a boss!");
  // updatePower(0); // ensure motors are off
  turnIndicatorLightOn();

  // play init song :D
  playInitSong();

  // print out two lines in case there
  // was garbage (noise) in serial setup
  Serial.println("\n");
  delay(100);
}

void loop(){
  long motor_delta = wait_MOTOR_CONTROL_TIMESTEP_ms();
  updateState(motor_delta, MOTOR_CONTROL_TIMESTEP);
  generateMotorCommand();
  wait_POSITION_CONTROL_TIMESTEP_ms();
  calculateCurrentError();
  calculateAccumulatedError();
  calculateDeltaError();
  printStatus();
  updateMotor();
  checkForPiCommand();
 }

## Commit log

2018-03-28 small update to readme on arduino
2018-04-04 adds functionality test for reset button
2018-04-04 utilize button for reset
2018-04-04 also dont need this stuff due to button
2018-04-05 handle bad responses from Arduino a bit better
2018-04-05 take two on receiving bad arduino messages
2018-04-05 adds buzzer to Arduino
    [arduino.ino, constants.cpp]
2018-04-05 arduino now handles unknown message type
2018-04-12 still working on dealing with the mysterious Arduino restarts
2018-04-13 trying a second button push to confirm we want to train.
2018-04-13 ensure motors off when done
2018-04-13 adding in a PID controller to make sure Im not insane
2018-04-13 fixes a long-time bug
    [arduino.ino]
2018-04-13 bit of work on the python element of the PID controller
2018-04-13 fixes to PID
2018-04-16 getting an inner motor control loop rockin
2018-04-18 working on libs and motor speed tuner
2018-04-23 edgeCount becomes long. fixes overflow
    [servoMotor.cpp]
2018-04-23 stores motorCommand
2018-04-23 each motor uses its own PID
2018-04-23 so tired
2018-04-24 trying another basic pid alternative
2018-04-25 pid puts out telemetry
2018-05-01 telemetry for pid
2018-05-01 IMU uses gyro for thetaDot, not discrete derivative
2018-05-02 lots of tweaks, system checks and checking to see if PWM is more reliable than Serial.
2018-05-05 adding comments to pid and pitalk
2018-05-07 add safety parans in case expressions used next to other expressions causes ambiguity
2018-05-08 get encoders system check working.
2018-05-08 tweaks to pwmMotor and servoMotor system checks
2018-05-08 getting servoMotor ironed out
2018-05-08 minor cleanup for getting serial motor control working again
2018-05-08 adds some telemetry for PID control
2018-05-10 added the wheel_pid script
2018-05-11 can specify if PID accumulator zeros when error crosses zero
2018-05-11 have EEPROM working for storing PID values.
2018-05-11 move EEPROM store/load functionality into pid.h
2018-05-11 want to send back PID values to RPi
2018-05-11 now we can report PID values back to pi
2018-05-14 adds an IMU system check
2018-05-14 fixing a buffer overflow error by popping
    [main.cpp]
2018-05-15 wip on calibration
2018-05-18 not needed now. New IMU is level
2018-05-18 did not like band pass filter
2018-05-21 getting beaker ready for reinforcement learning (again)
    [main.cpp]
2018-05-22 allows arduino to receive acceleration as a means to change targer rads / sec
2018-05-22 limit power to +- 0.5 and send as acceleration not absolute rads/sec
2018-05-22 fix arduinos reset function
2018-05-30 adds in the gym for beaker
    [beaker.urdf]
2018-05-31 working on beaker bot states
    [beaker.urdf]
2018-05-31 figured out how to calculate theta dot in pybullet
    [beaker.urdf]
2018-06-01 making the robot easier to see
    [beaker.urdf]
2018-06-03 still messing around
    [beaker.urdf]
2018-06-03 removing silly print statements
2018-06-05 minor urdf changes
    [beaker.urdf]
2018-06-05 use local beaker.urdf and go with 50hz
2018-06-05 camera follows beaker, getting PID working
2018-06-06 fix minor issue with low level serial motor
2018-06-07 the wheel stop experiment
    [beaker.urdf, beakerWithTrainingWheels.urdf, otherBalancer.urdf]
2018-06-20 more prep for ddpg in real robot
    [beaker.urdf]
2018-06-22 removed old controllers
    [beaker.urdf]
2018-06-22 clarification of PID readme
2018-06-22 fix small inconsistency in beaker.urdf
    [beaker.urdf]
2018-06-22 use total phi for pid
2018-07-06 add URDF builders
2018-07-06 finishes to the beaker URDF builder
    [beaker.urdf, beaker_safe.urdf]
2018-07-06 move comments around
    [beaker.urdf]
2018-07-06 fix urdf builder
    [beaker.urdf]
2018-07-12 working on urdf again
    [beaker.urdf, beaker_safe.urdf]
2018-08-20 use the non backlash urdf file
    [beaker.urdf]
2018-08-22 look at how many times we checked for wheels spinning
2018-08-22 kick off pid client
2018-08-22 update power in arduino.py
2018-08-22 loop pid client
2018-08-22 getting pi pid timing right
2018-08-22 retuning PID for rpi PID control
2018-08-23 tweaks to pid client
2018-08-23 fixes arduino typo
2018-08-23 have PID working via rPI polling, mostly
2018-08-23 remove prints
2018-08-27 first draft at using message id for arduino
2018-08-27 move messageId handling on rPi to arduino.py
2018-08-27 a little bluetooth groundcontrol system check
2018-08-31 ground control arduino header file, in case we need it
2018-08-31 rpi pid printouts
2018-08-31 move PID values out to txt file
    [pid_values.yml]
2018-08-31 adds in xpos centering
    [pid_values.yml]
2018-09-12 remove print statements
